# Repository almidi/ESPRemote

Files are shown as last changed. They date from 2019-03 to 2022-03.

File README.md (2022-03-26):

# ESPRemote
### VER 0.1

A simple WiFI remote controller using the ESP8266 SoC.

The goal of this project is the creation of a simple to use WiFi remote controller aimed at usage with the numerous home automation suites available, such as _[HomeAssistant](https://www.home-assistant.io)_ and _[OpenHab](https://www.openhab.org)_.

The system utilizes an _[Espressif ESP-12](https://docs.platformio.org/en/latest/boards/espressif8266/esp12e.html)_ module coupled with an _[MCP73831T](https://www.google.gr/url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)_ chip for battery management and an _[AP2112K](https://www.google.gr/url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)_ LDO voltage regulator.

## Configurations

The board can be configured as a battery powered remote control, or as a DC powered button panel. To achieve this a jumper was added (SJ2) to select between battery and direct USB power. A second jumper was also added (JP2) to bypass the power switch. Using the above jumpers, the BMS circuit can be completely ignored and left unpopulated in case the device is inteded for always pluged-in use from a 5V DC power supply.

## Firmware

Using the _[Espressif ESP-12](https://docs.platformio.org/en/latest/boards/espressif8266/esp12e.html)_ module offers great flexibility in existing firmware options. Currently the _[ESPHome](https://esphome.io/index.html)_ firmware is used, designed for seemless intergation with the _[HomeAssistant](https://www.home-assistant.io)_ platform.

Due to the device not beign intended as a development board, an FTDI chip was excluded from the design, leaving the need for a small 6-pin SH 1.0mm micro jst connector as a UART interface.

**Uploading new firmware requires the pin D0 and GND of the UART connector to be tied together.** After doing so the device must be reset, setting it in download mode and enabling new firmware to be uploaded. **This can also be achieved holding down the 4th button before powering on the device**.

## I/O

| | Pin |
|---|---|
| Button 1 | GPIO5  |
| Button 2 | GPIO4  |
| Button 3 | GPIO12 |
| Button 4 | GPIO0  |
| Button 5 | GPIO13 |
| Battery Voltage | ADC |
| Status Led | GPIO16 |

## PCB

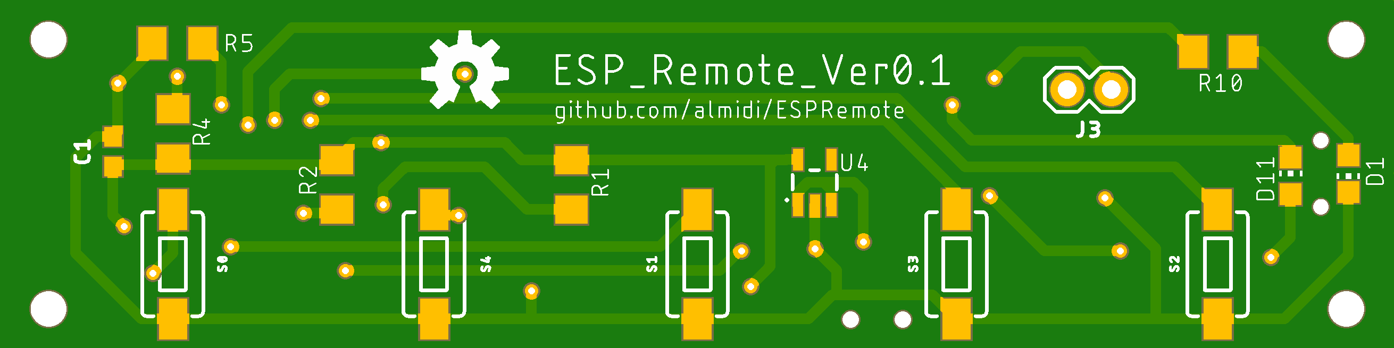
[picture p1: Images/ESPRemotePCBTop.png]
PCB Top Layer Top Layer


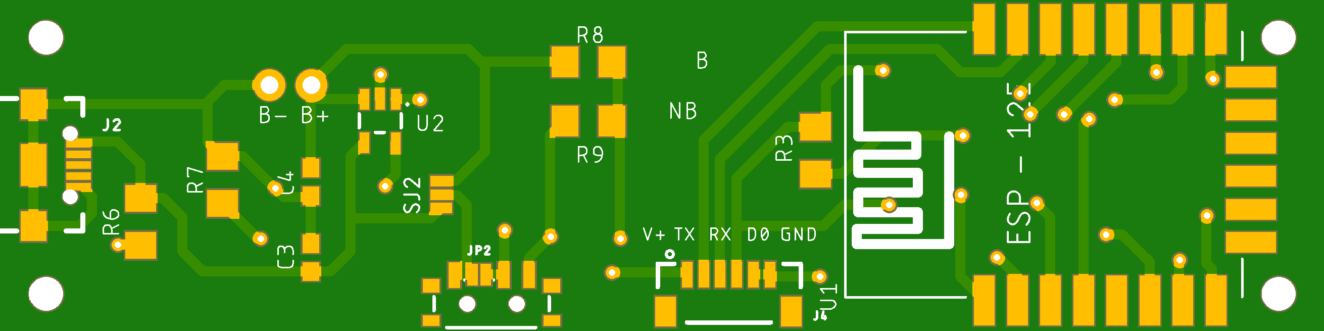
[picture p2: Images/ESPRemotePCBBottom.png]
PCB Bottom Layer Bottom Layer


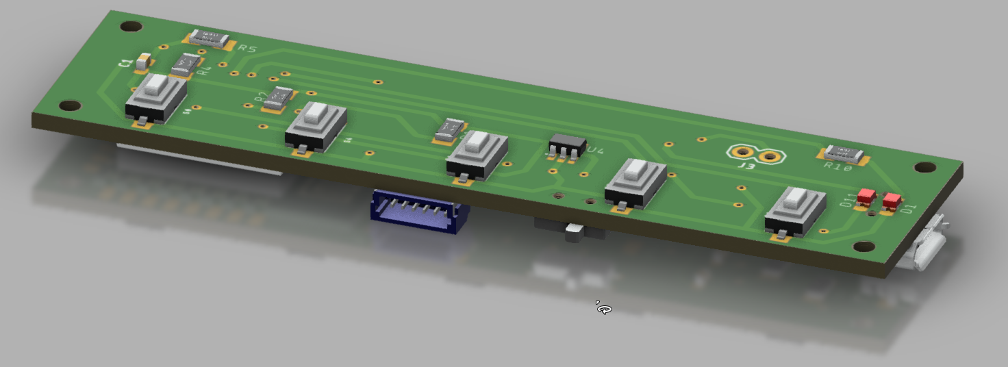
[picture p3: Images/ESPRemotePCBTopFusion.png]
PCB 3D Model


## Enclosure

The enclosure is designed to incorporate a single 400mAh li-po cell and be 3D printed in two parts.

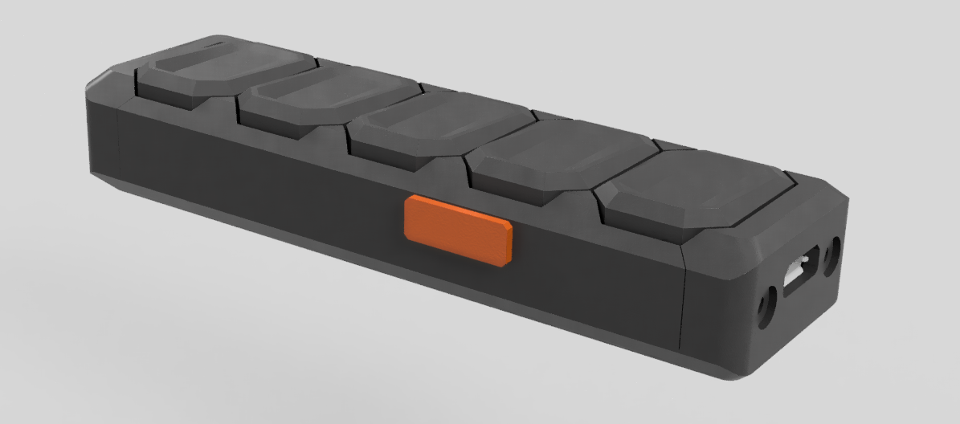
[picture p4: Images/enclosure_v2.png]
3D Model Enclosure 3D Model


## Future Work

- Incorporate a small 128x64 OLED screen.
- Add an IR transmitter to the design, so that the controller can be used with existing household devices.
- Add an accelerometer for gesture control.
- Design a better, prettier and easier to hold enclosure.

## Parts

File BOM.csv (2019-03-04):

Part | Value | Device | Package | Description | PROD_ID | SF_ID | SF_SKU | SPICEPREFIX | VALUE
C1 | 10UF | 10UF | C0603 | 10.0µF ceramic capacitors
C3 | 10UF | 10UF | C0603 | 10.0µF ceramic capacitors
C4 | 10UF | 10UF | C0603 | 10.0µF ceramic capacitors
D1 | BLUE | LEDCHIP-LED0805 | CHIP-LED0805 | LED
D11 | RED | LEDCHIP-LED0805 | CHIP-LED0805 | LED
J2 |  | USB_MICRO-B_FEMALE-SMT | USB-B-MICRO-SMD | USB Type Micro-B Connector | CONN-11752
J3 |  | CONN_02 | 1X02 | Multi connection point. Often used as Generic Header-pin footprint for 0.1 inch spaced/style header connections
J4 |  | CONN_06SMD-1MM | 1X06-1MM | Multi connection point. Often used as Generic Header-pin footprint for 0.1 inch spaced/style header connections | CONN-08249 | GPS-00579
JP2 | JUMPER-SMT_2_NO_NO-SILK | JUMPER-SMT_2_NO_NO-SILK | SMT-JUMPER_2_NO_NO-SILK | Normally open jumper
R1 | 10k | R-US_R1206 | R1206 | RESISTOR, American symbol
R2 | 10k | R-US_R1206 | R1206 | RESISTOR, American symbol
R3 | 10k | R-US_R1206 | R1206 | RESISTOR, American symbol
R4 | 10k | R-US_R1206 | R1206 | RESISTOR, American symbol
R5 | 10k | R-US_R1206 | R1206 | RESISTOR, American symbol
R6 | 330 | R-US_R1206 | R1206 | RESISTOR, American symbol
R7 | 2.0k | R-US_R1206 | R1206 | RESISTOR, American symbol
R8 | 10k | R-US_R1206 | R1206 | RESISTOR, American symbol
R9 | 10k | R-US_R1206 | R1206 | RESISTOR, American symbol
R10 | 330 | R-US_R1206 | R1206 | RESISTOR, American symbol
S0 | SMD-SWITCH-6.2MM | MOMENTARY-SWITCH-SPST-SMD-6.0X3.5MM | TACTILE_SWITCH_SMD_6.0X3.5MM | Momentary Switch (Pushbutton) - SPST | SWCH-00815 |  | COM-08229
S1 | SMD-SWITCH-6.2MM | MOMENTARY-SWITCH-SPST-SMD-6.0X3.5MM | TACTILE_SWITCH_SMD_6.0X3.5MM | Momentary Switch (Pushbutton) - SPST | SWCH-00815 |  | COM-08229
S2 | SMD-SWITCH-6.2MM | MOMENTARY-SWITCH-SPST-SMD-6.0X3.5MM | TACTILE_SWITCH_SMD_6.0X3.5MM | Momentary Switch (Pushbutton) - SPST | SWCH-00815 |  | COM-08229
S3 | SMD-SWITCH-6.2MM | MOMENTARY-SWITCH-SPST-SMD-6.0X3.5MM | TACTILE_SWITCH_SMD_6.0X3.5MM | Momentary Switch (Pushbutton) - SPST | SWCH-00815 |  | COM-08229
S4 | SMD-SWITCH-6.2MM | MOMENTARY-SWITCH-SPST-SMD-6.0X3.5MM | TACTILE_SWITCH_SMD_6.0X3.5MM | Momentary Switch (Pushbutton) - SPST | SWCH-00815 |  | COM-08229
S5 |  | SWITCH-SPDT-SMD-RIGHT-ANGLE | SWITCH_SPST_SMD_A | Single Pole, Double Throw (SPDT) Switch | SWCH-10651 |  | COM-10860
SJ2 | JUMPER-SMT_3_NO_NO-SILK | JUMPER-SMT_3_NO_NO-SILK | SMT-JUMPER_3_NO_NO-SILK | Normally open jumper
U1 |  | ESP12ESMD | ESP12E-SMD | ESP12E Module |  |  |  | X
U2 | MCP73831 | MCP73831 | SOT23-5 | MCP73831T Li-Ion, Li-Pol Controller | IC-09995
U4 | 3.3V | V_REG_AP2112K-3.3V | SOT23-5 | AP2112 - 600mA CMOS LDO Regulator w/ Enable | VREG-12457 |  |  |  | 3.3V

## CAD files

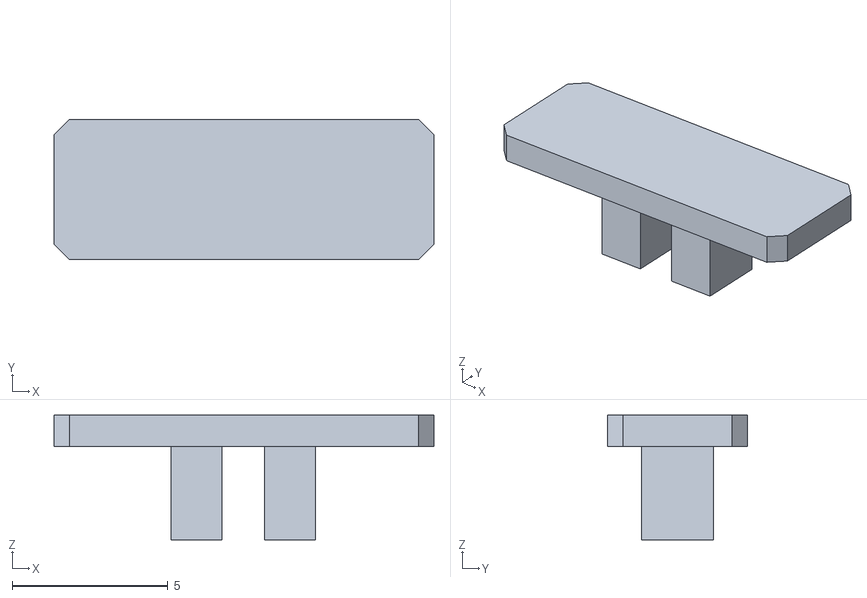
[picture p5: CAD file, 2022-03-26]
Enclosure/WithBattery_V2/Switch.stl
12.2 x 4.50 x 4.00

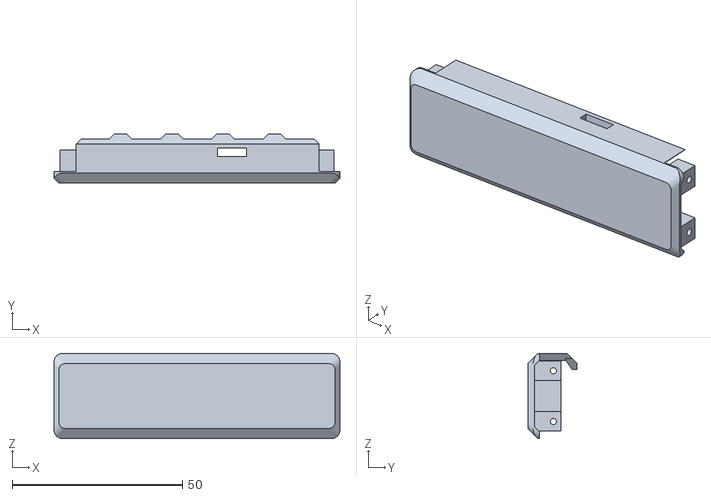
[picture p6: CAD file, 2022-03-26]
Enclosure/WithBattery_V2/Base.stl
84.0 x 14.5 x 25.0

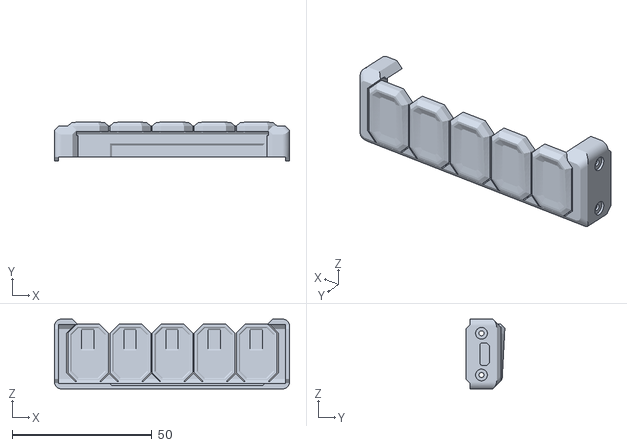
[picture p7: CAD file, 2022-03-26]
Enclosure/WithBattery_V2/Body.stl
84.0 x 13.9 x 25.0

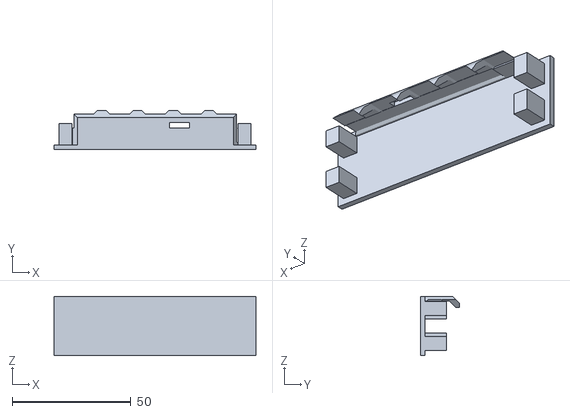
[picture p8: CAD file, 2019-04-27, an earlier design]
Enclosure/WithBattery/Base.stl
85.0 x 16.5 x 25.0

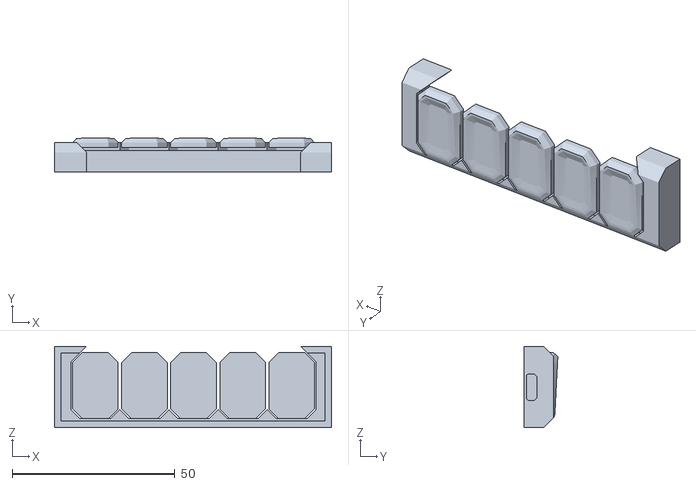
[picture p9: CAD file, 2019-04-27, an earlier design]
Enclosure/WithoutBattery/Body.stl
85.0 x 10.4 x 25.0

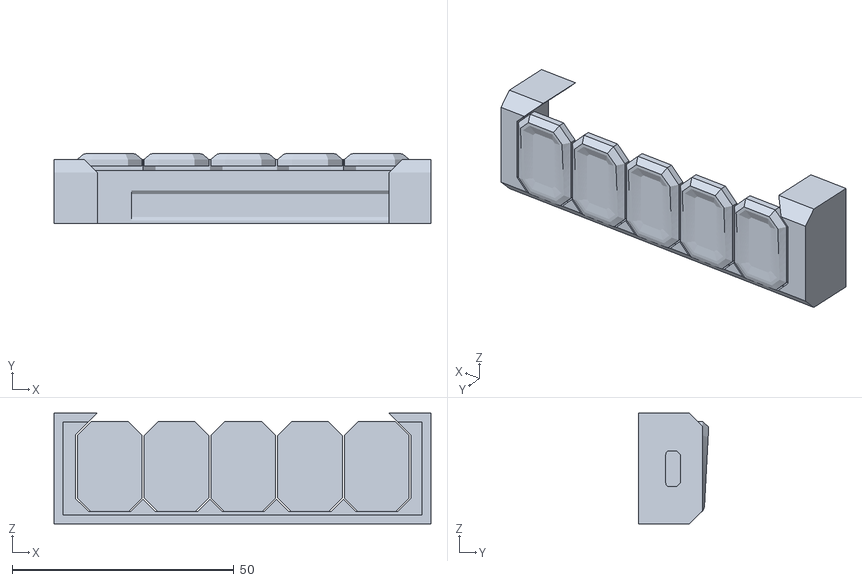
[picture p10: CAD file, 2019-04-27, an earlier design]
Enclosure/WithBattery/Body.stl
85.0 x 15.9 x 25.0

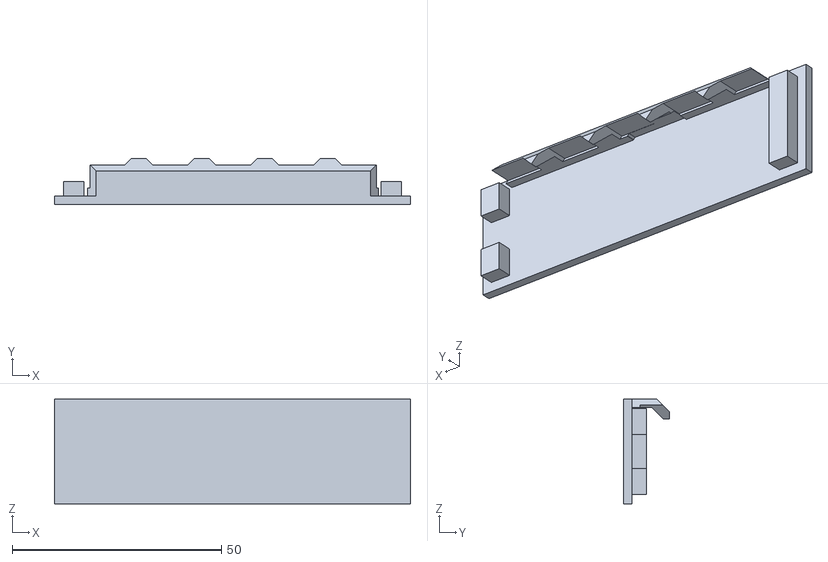
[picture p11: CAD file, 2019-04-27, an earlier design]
Enclosure/WithoutBattery/Base.stl
85.0 x 11.0 x 25.0

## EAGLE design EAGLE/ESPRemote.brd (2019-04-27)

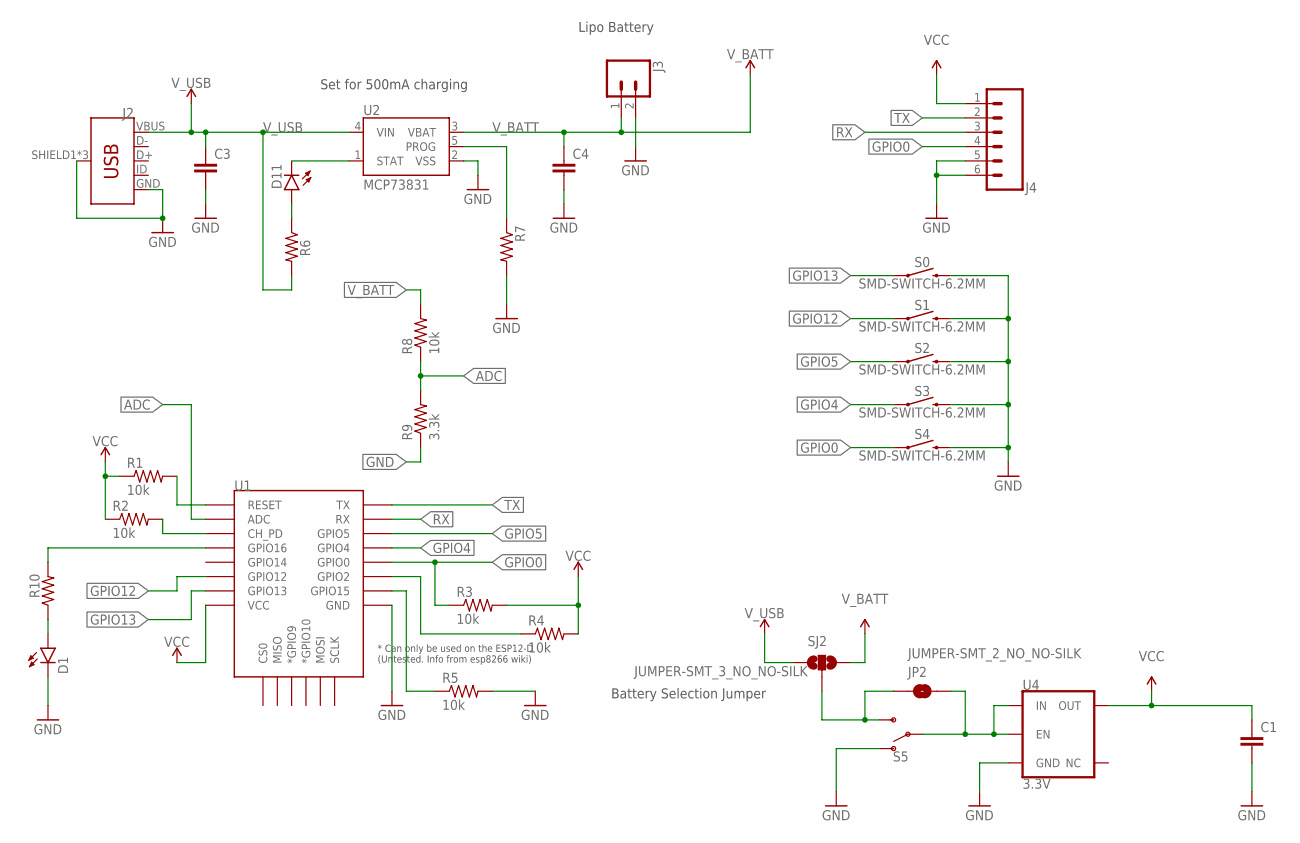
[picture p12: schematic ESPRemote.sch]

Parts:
C1, C3, C4: 10UF; C0603
D1: BLUE; CHIP-LED0805
D11: RED; CHIP-LED0805
J2: USB_MICRO-B_FEMALE-SMT; USB-B-MICRO-SMD
J3: CONN_02; 1X02
J4: CONN_06SMD-1MM; 1X06-1MM
JP2: JUMPER-SMT_2_NO_NO-SILK; SMT-JUMPER_2_NO_NO-SILK
R1, R2, R3, R4, R5, R8: 10k; R1206
R6: 1k; R1206
R7: 2.0k; R1206
R9: 3.3k; R1206
R10: 330; R1206
S0, S1, S2, S3, S4: SMD-SWITCH-6.2MM; TACTILE_SWITCH_SMD_6.0X3.5MM
S5: SWITCH-SPDT-SMD-RIGHT-ANGLE; SWITCH_SPST_SMD_A
SJ2: JUMPER-SMT_3_NO_NO-SILK; SMT-JUMPER_3_NO_NO-SILK
U1: ESP12ESMD; ESP12E-SMD
U2: MCP73831; SOT23-5
U4: 3.3V; SOT23-5

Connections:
ADC: R8.1, R9.2, U1.ADC
GND: C1.2, C3.2, C4.2, D1.C, J2.GND, J2.SHIELD1 (SHIELD), J2.SHIELD2 (SHIELD), J2.SHIELD3 (SHIELD), J3.2, J4.5, J4.6, R5.2, R7.2, R9.1, S0.2, S1.2, S2.2, S3.2, S4.2, S5.1 (O), U1.GND, U2.2 (VSS), U4.2 (GND)
GPIO0: J4.4, R3.1, S4.1, U1.GPIO0
GPIO4: S3.1, U1.GPIO4
GPIO5: S2.1, U1.GPIO5
GPIO12: S1.1, U1.GPIO12
GPIO13: S0.1, U1.GPIO13
unnamed: JP2.2, S5.2, U4.1 (IN), U4.3 (EN)
unnamed: R1.2, U1.RESET
unnamed: D11.A, R6.1
unnamed: R2.2, U1.CH_PD
unnamed: R4.1, U1.GPIO2
unnamed: JP2.1, S5.3 (S), SJ2.2
unnamed: R5.1, U1.GPIO15
unnamed: R10.2, U1.GPIO16
unnamed: D1.A, R10.1
PROG: R7.1, U2.5 (PROG)
RX: J4.3, U1.RXD0 (RX)
STAT: D11.C, U2.1 (STAT)
TX: J4.2, U1.TXD0 (TX)
VCC: C1.1, J4.1, R1.1, R2.1, R3.2, R4.2, U1.VCC, U4.5 (OUT)
V_BATT: C4.1, J3.1, R8.2, SJ2.3, U2.3 (VBAT)
V_USB: C3.1, J2.VBUS, R6.2, SJ2.1, U2.4 (VIN)

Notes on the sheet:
Set for 500mA charging
Battery Selection Jumper
Lipo Battery

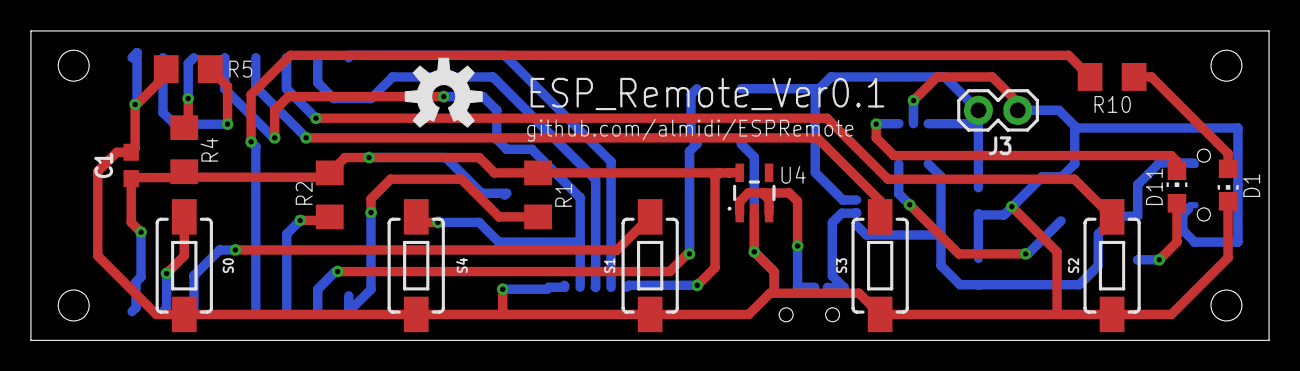
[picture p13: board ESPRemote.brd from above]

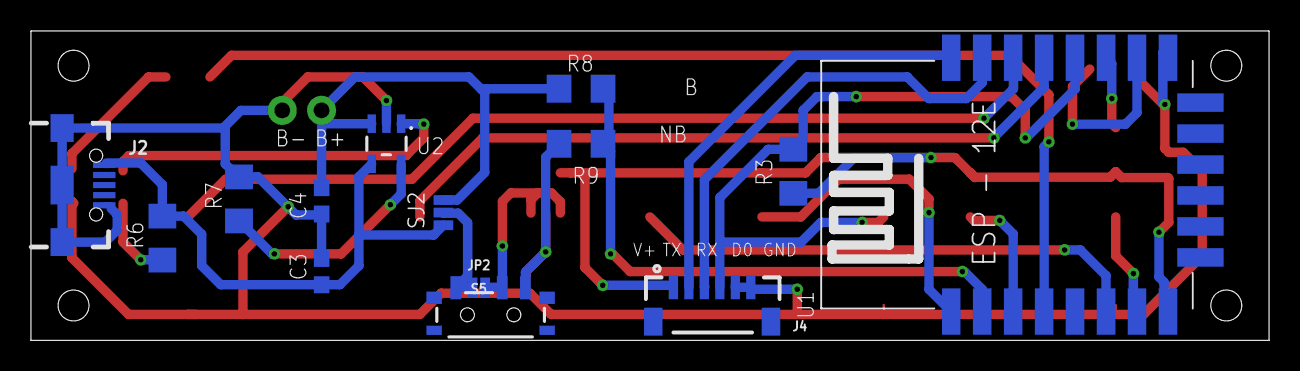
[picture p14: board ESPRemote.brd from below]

Board: 2 copper layers, 80.0 x 20.0 mm, 30 parts (14 on the bottom side), 23 nets.

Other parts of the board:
U$2: OSHW-LOGO-M

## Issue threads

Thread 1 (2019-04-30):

Cannot import BOM file to lcsc.com

Zolli, 2019-04-30:
While i try to import the BOM.csv file into lcsc.com the processing on the site is broken, and cannot properly split the csv into columns. This probably caused by a mistake in the csv file

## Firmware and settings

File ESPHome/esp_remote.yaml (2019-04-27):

esphomeyaml:
  name: esp_remote
  platform: ESP8266
  board: esp12e

wifi:
  # Wifi Configuration
  ssid: '#ssid'
  password: '#password'
  manual_ip:
   # Set this to the IP of the ESP
   static_ip: ip.of.remote
   # Set this to the IP address of the router. Often ends with .1
   gateway: ip.of.gateway
   # The subnet of the network. 255.255.255.0 works for most home networks.
   subnet: sub.net.mask
  power_save_mode: none
  fast_connect: on


# Enable logging
logger:
  level: 'none'

# Enable Home Assistant API
api:
  password: '#api_password'

ota:
  password: '#ota_password'

# Status LED GPIO
output:
  - platform: esp8266_pwm
    pin: 16
    frequency: 500 Hz
    id: status_led

# Status LED
light:
  - platform: monochromatic
    name: "STATUS"
    id: status
    output: status_led
    gamma_correct: 0
    default_transition_length: 20ms
    internal: true

# Buttons
binary_sensor:
  - platform: gpio
    pin:
      number: 13
      mode: INPUT_PULLUP
      inverted: True
    name: "Button 0"
    id: btn0
    filters:
      - delayed_off: 10ms



  - platform: gpio
    pin:
      number: 0
      mode: INPUT_PULLUP
      inverted: True
    name: "Button 1"
    id: btn1
    filters:
        - delayed_off: 10ms

  - platform: gpio
    pin:
      number: 12
      mode: INPUT_PULLUP
      inverted: True
    name: "Button 2"
    id: btn2
    filters:
        - delayed_off: 10ms

  - platform: gpio
    pin:
      number: 4
      mode: INPUT_PULLUP
      inverted: True
    name: "Button 3"
    id: btn3
    filters:
        - delayed_off: 10ms

  - platform: gpio
    pin:
      number: 5
      mode: INPUT_PULLUP
      inverted: True
    name: "Button 4"
    id: btn4
    filters:
        - delayed_off: 10ms

# Status ON on button press
interval:
  - interval: 20ms
    then:
    - if:
        condition:
          or:
            - binary_sensor.is_on: btn0
            - binary_sensor.is_on: btn1
            - binary_sensor.is_on: btn2
            - binary_sensor.is_on: btn3
            - binary_sensor.is_on: btn4
        then:
          - light.turn_on: 
              id: status  
              brightness: 5%
        else:
          - light.turn_off: status

# Battery level sensor
sensor:
  - platform: adc
    pin: GPIO17
    name: "Battery Charge"
    unit_of_measurement: "%"
    update_interval: 60s
    filters:
      #value mapping
      - lambda: return (x - 0.8)/(0.2) * (100.0);

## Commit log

2019-04-27 Updated Enclosures
    [Base.stl, Body.stl, ESPRemote.brd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]
2022-03-26 v2 enclosure
    [Base.stl, Body.stl, Switch.stl]

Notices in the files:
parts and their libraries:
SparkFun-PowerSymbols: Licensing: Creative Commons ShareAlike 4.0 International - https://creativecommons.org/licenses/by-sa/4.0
